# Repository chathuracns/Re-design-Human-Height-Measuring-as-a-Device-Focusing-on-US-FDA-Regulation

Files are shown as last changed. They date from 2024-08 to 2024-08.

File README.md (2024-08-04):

# Re-design-Human-Height-Measuring-as-a-Device-Focusing-on-US-FDA-Regulation

## **Device Classification and Premarket Notification:**

We have classified the device as a Class II medical device. In accordance with FDA regulations, a Premarket Notification (510(k)) submission is required for Class II devices. We have determined that our device is substantially equivalent to a legally marketed predicate device. This determination involved a comprehensive analysis of existing products, identifying both similarities and differences between them and our device.

## **Good Manufacturing Practices (GMP):**

We are in full compliance with the FDA's Quality System Regulation (QSR), which encompasses requirements for design controls, focusing on user safety, production, and process controls. We have adhered to rigorous documentation practices from the outset to ensure comprehensive record-keeping.

## **Design Controls:**

**Purpose:** Design controls are implemented to ensure the device is designed to meet user requirements and regulatory standards while mitigating risks.

- **Design and Development Planning:** We have completed three prototype iterations: a demonstration prototype, an alpha prototype, and a limited batch production run of 15 devices. Each prototype underwent three test cycles, leading to iterative improvements in quality.

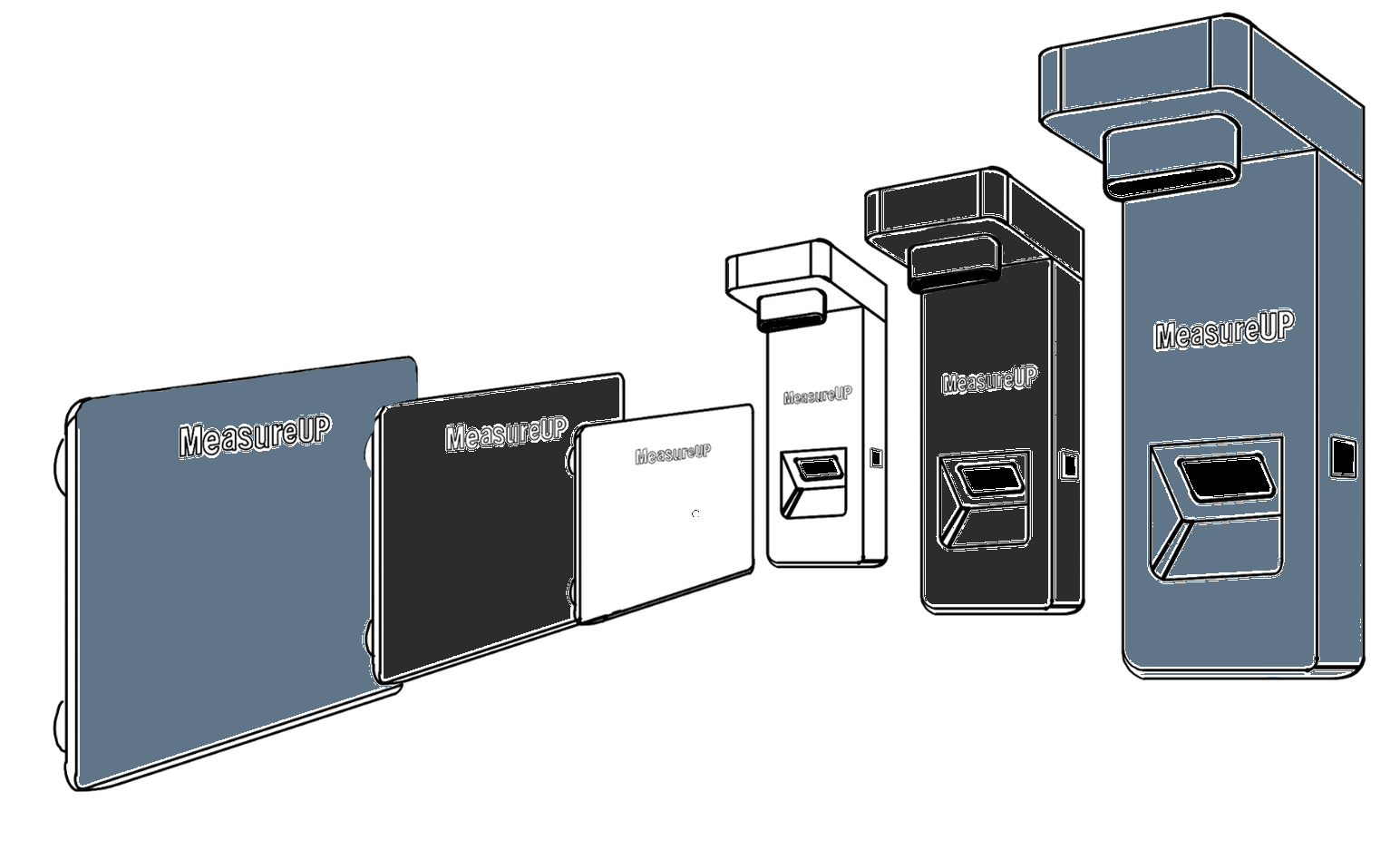
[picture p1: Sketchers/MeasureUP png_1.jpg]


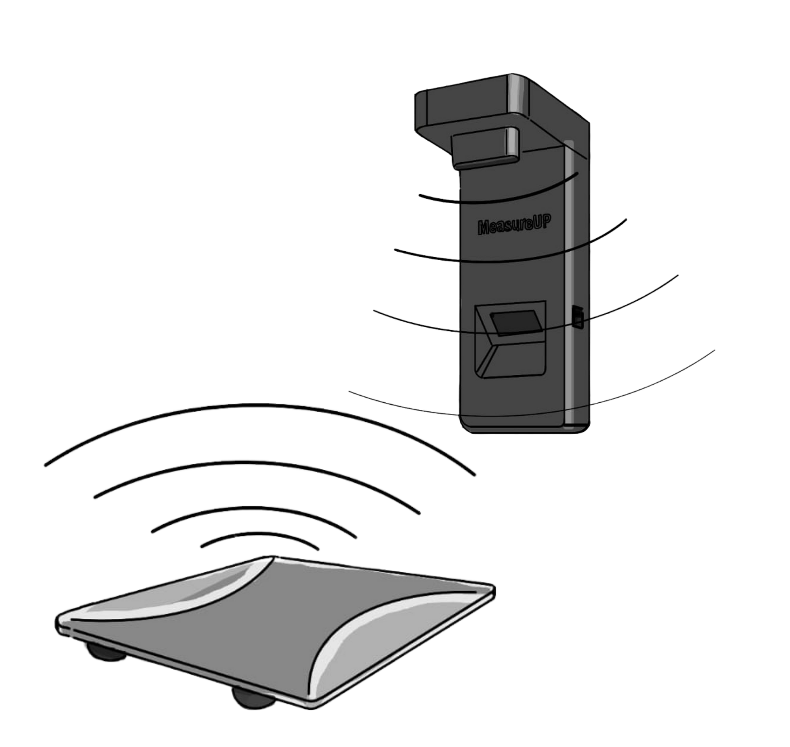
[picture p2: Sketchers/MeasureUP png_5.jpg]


- **Design Input:** The design was primarily developed to meet UNICEF's height measurement requirements for children, targeting a precision of approximately 1mm. Initially, the device exhibited a precision of 3cm, and we are working towards further refinement to meet these precision standards.
  
- **Design Output:** Documentation demonstrates that the design meets user requirements and regulatory criteria. We have documented improvements through three test cycles and various prototype stages.

- **Design Verification and Validation:** We ensure that the design meets all specified requirements through rigorous testing and evaluation. Achieving a precision of 3cm represents significant progress given the device's initial specifications.

## **Production and Process Controls:**

- **Process Validation:** The product enclosure has been optimized to maintain consistent printing quality.
  
- **Control of Production and Process Changes:** We have selected reputable production partners and documented the selection process accordingly.
  
- **Production Records:** We place significant emphasis on maintaining detailed production records.

- **Labeling:** The device adheres to appropriate labeling requirements, including user instructions, indications for use, and necessary warnings or precautions.

## **Document Controls:**

**Purpose:** We ensure that all documents related to the device’s design, manufacturing, and quality are properly controlled and maintained, particularly in relation to managing a 500,000 LKR grant which necessitated the management of approximately 100 documents.

**Document Creation and Review:** We develop and review key documents such as design specifications, manufacturing instructions, and quality control procedures. For instance, we have created and reviewed a Standard Operating Procedure (SOP) for sensor calibration, ensuring it is approved by the quality team.

**Document Changes:** We implement a structured process for managing document changes. 

**Document Storage and Retrieval:** Documents are stored in a secure, organized manner to facilitate easy retrieval. Electronic records of design and production documents are maintained in a document management system with version control.

---

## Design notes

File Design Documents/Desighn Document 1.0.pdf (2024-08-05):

# Improvements

1.Edges Design Modification:

Make the edges curved like this and remove the slope on the other side.

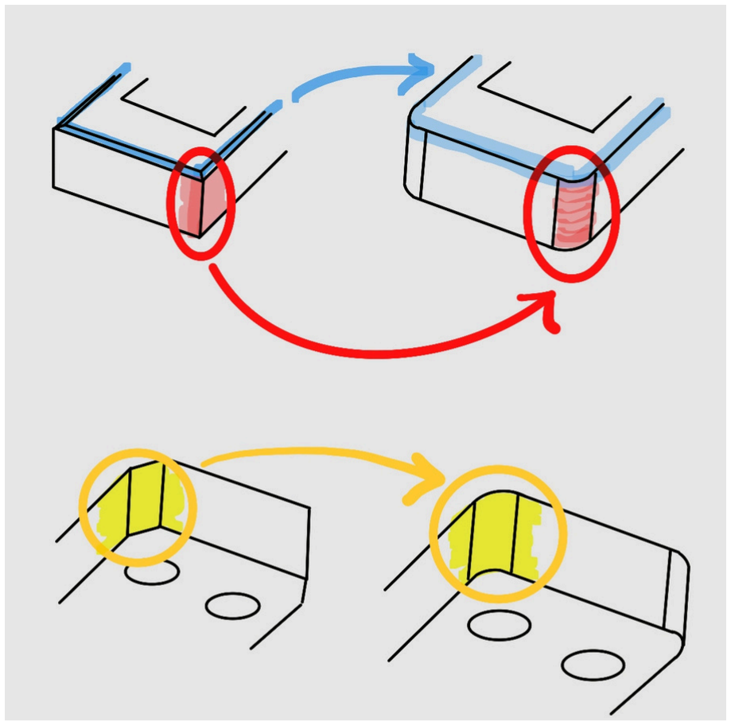
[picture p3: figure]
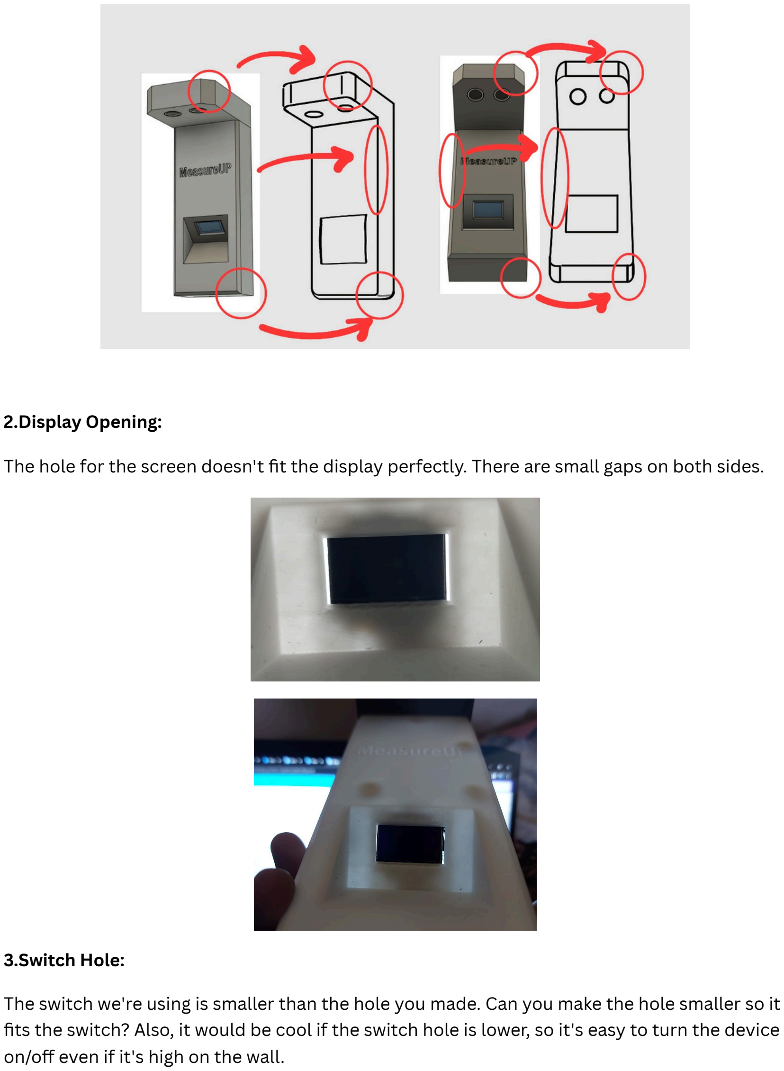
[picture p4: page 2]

2.Display Opening:

The hole for the screen doesn't fit the display perfectly. There are small gaps on both sides.

3.Switch Hole:

The switch we're using is smaller than the hole you made. Can you make the hole smaller so it fits the switch? Also, it would be cool if the switch hole is lower, so it's easy to turn the device on/off even if it's high on the wall.

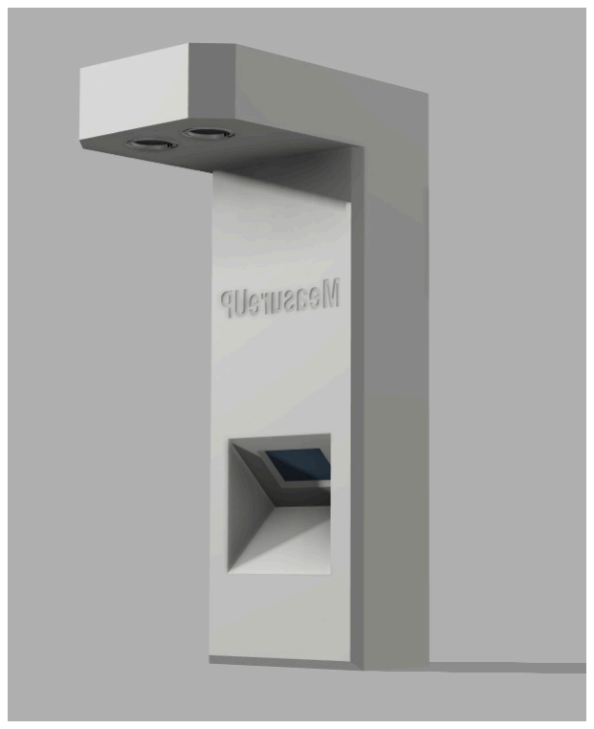
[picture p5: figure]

4.Battery Hole:

The magnets on both sides of the battery hole make it hard to put in the battery. Can you move one magnet up and the other down, so there's space in the middle for the battery?

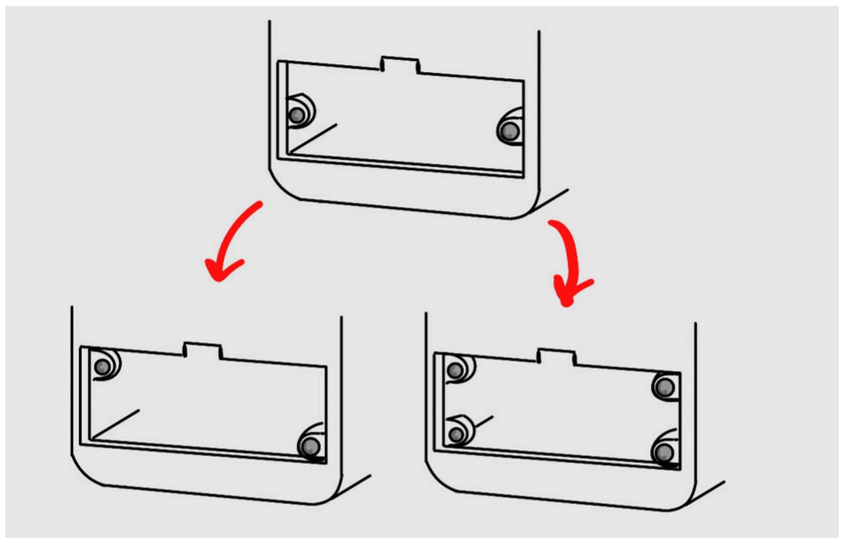
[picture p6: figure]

5.Back Cover:

The back cover only has three screws, and it bends when you press it. Maybe add more screws or move them around?

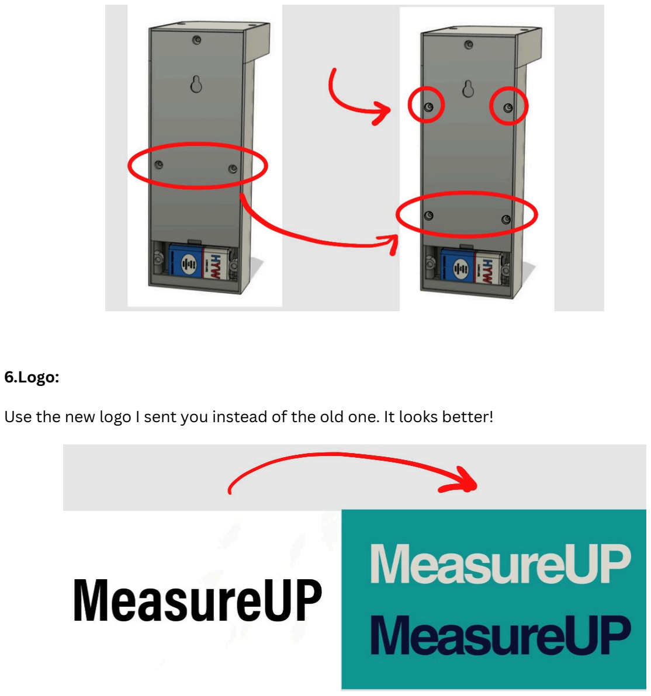
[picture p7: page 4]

6.Logo:

Use the new logo I sent you instead of the old one. It looks better!

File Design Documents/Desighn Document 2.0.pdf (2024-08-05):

1.Need to add an extended part to the ultrasonic sensor holes in order to control its sound beam. A sample SolidWorks file is attached below to provide an idea of its structure, but we need to figure out how to mount it to the previous structure. The dimensions of the clip are the same as those provided in the SolidWorks design.

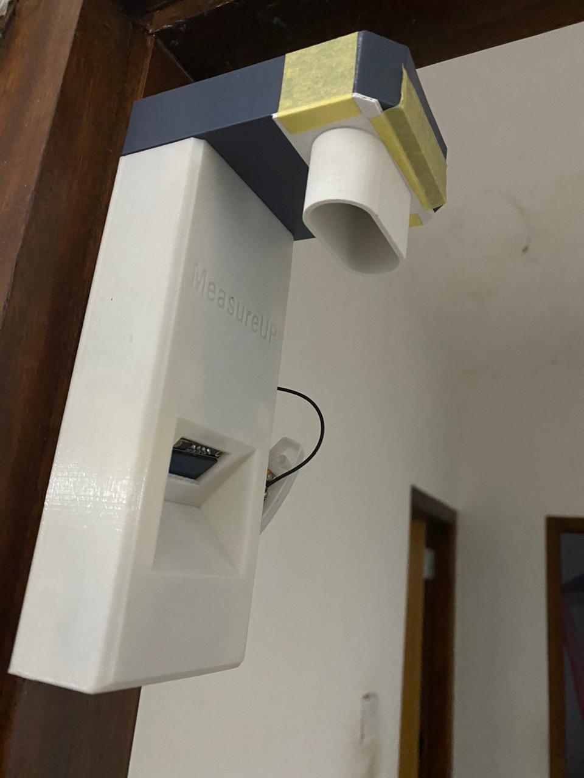
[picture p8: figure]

2.Need to modify the vertices and some edges of the display hole. Here is how it should be adjusted.

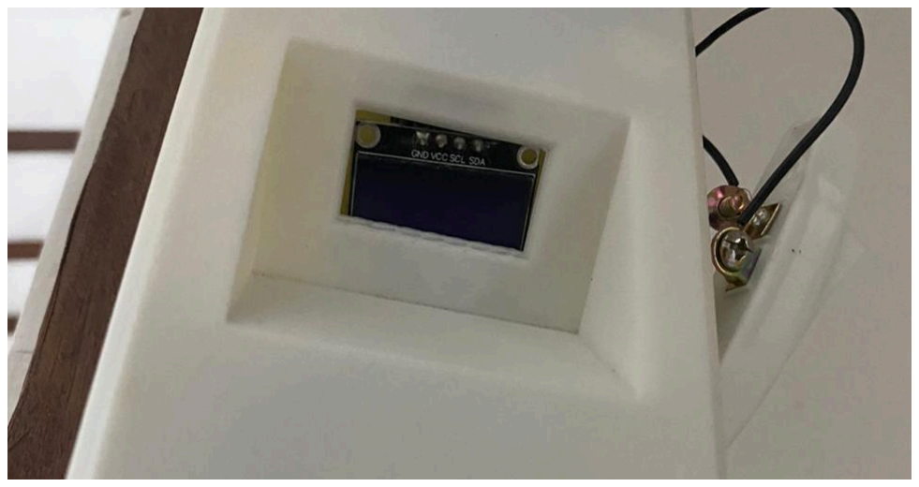
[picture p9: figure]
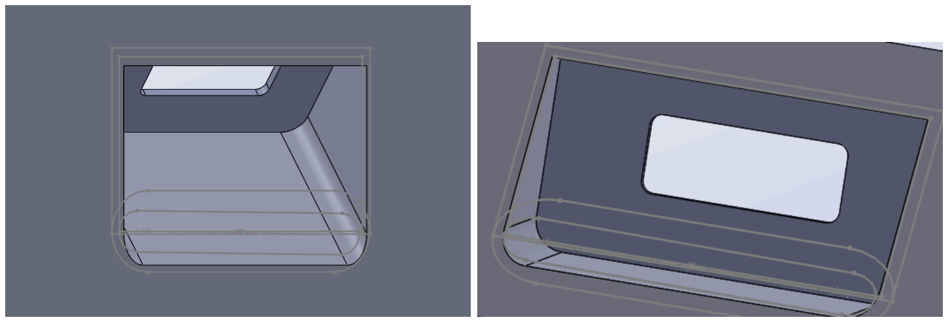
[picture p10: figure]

3.No need to change the dimensions of the OLED hole, as the newly ordered OLED fits well into it.

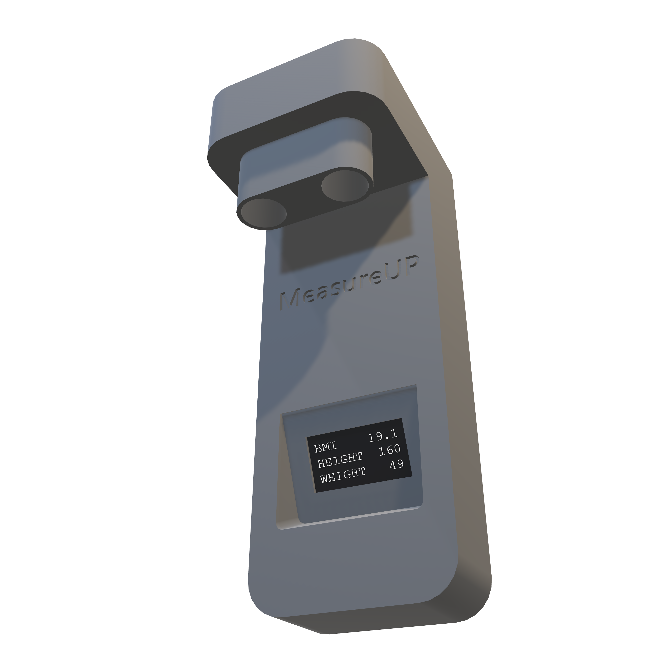
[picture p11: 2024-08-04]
Design Documents/Picture2.png

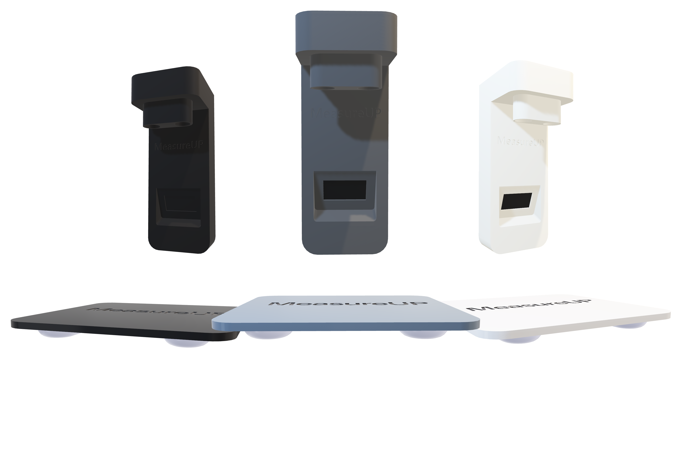
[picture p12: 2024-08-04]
Design Documents/Picture1.png

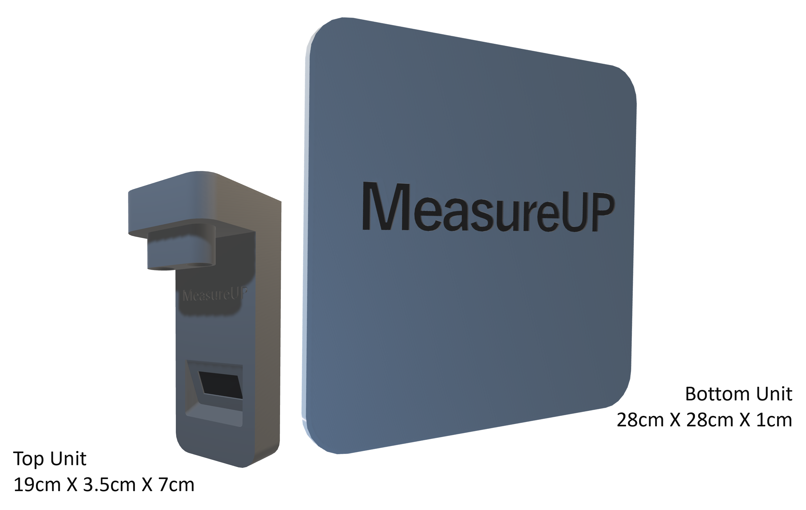
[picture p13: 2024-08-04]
Design Documents/Picture4.png

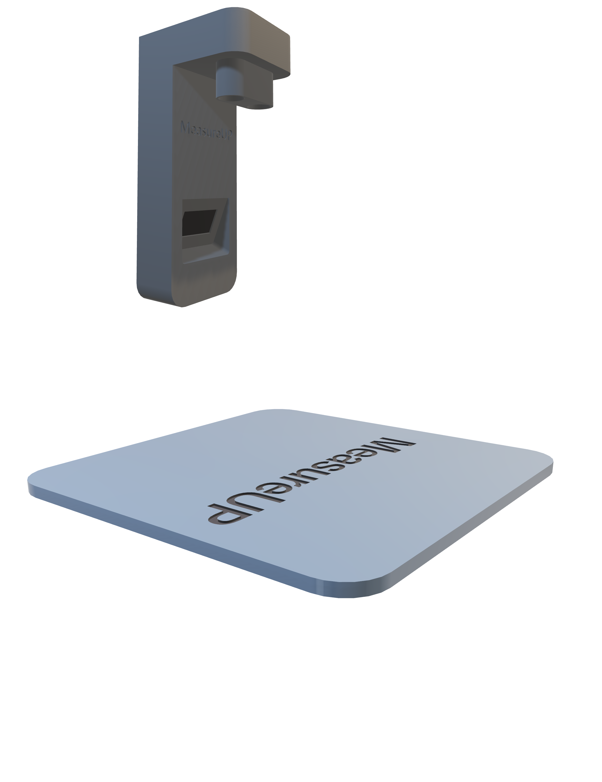
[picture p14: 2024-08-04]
Design Documents/Picture7.png

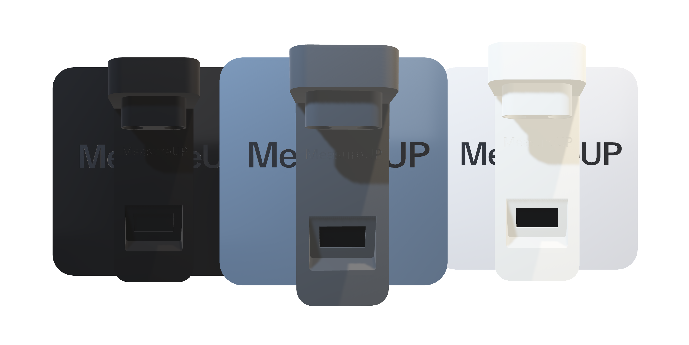
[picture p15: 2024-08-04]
Design Documents/Picture5.png

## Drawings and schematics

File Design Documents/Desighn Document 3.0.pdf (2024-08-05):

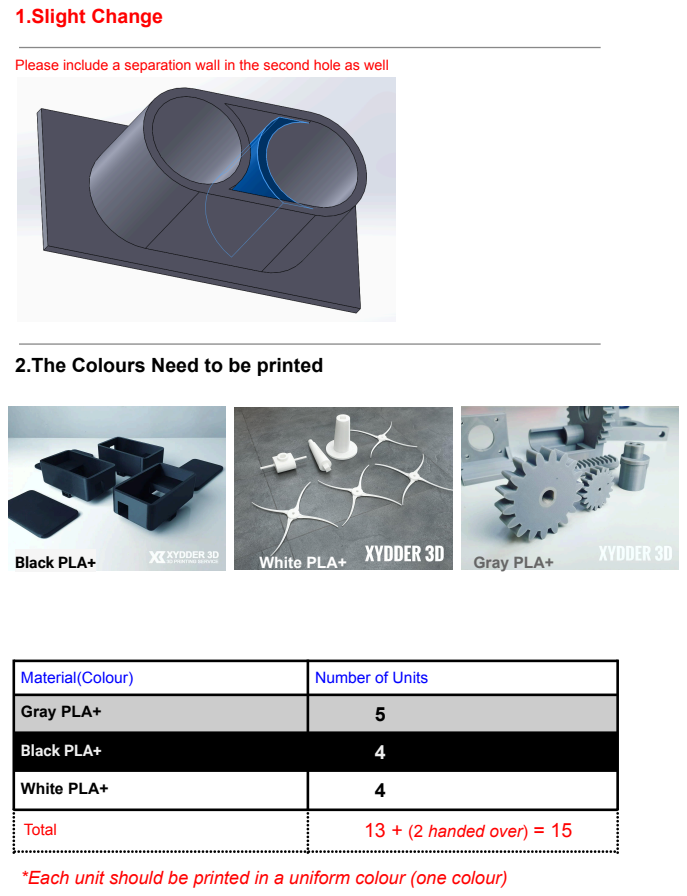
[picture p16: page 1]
1.Slight Change; Black PLA+; White PLA+; Gray PLA+; Total; 13 + (2 handed over) = 15

Please include a separation wall in the second hole as well

2.The Colours Need to be printed

Material(Colour) | Number of Units

Gray PLA+ | 5

Black PLA+ | 4

White PLA+ | 4

*Each unit should be printed in a uniform colour (one colour)

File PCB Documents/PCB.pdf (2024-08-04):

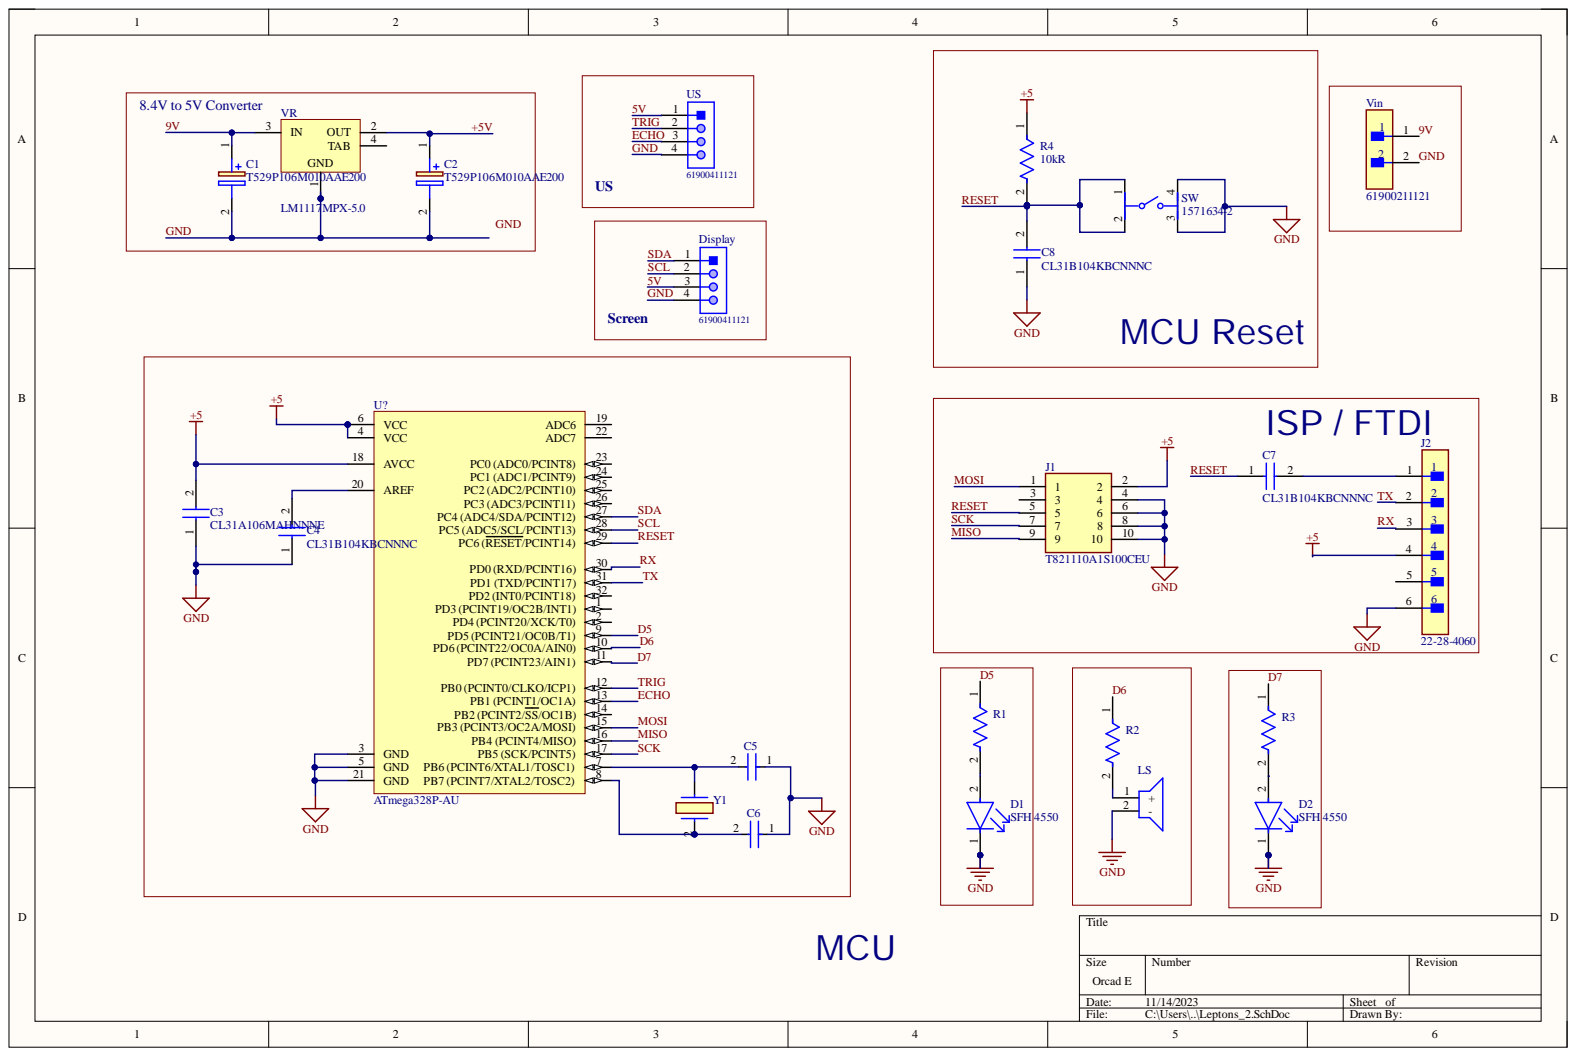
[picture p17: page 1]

1 8 | 2 3
2 0 | 2 4

Size Orcad E | Nu mb er | Revis i o n

Date: 1 1/1 4 /2 0 2 3 | Sheet o f
File: C:\User s\..\Lepto n s _ 2.S ch D o c | Drawn B y :

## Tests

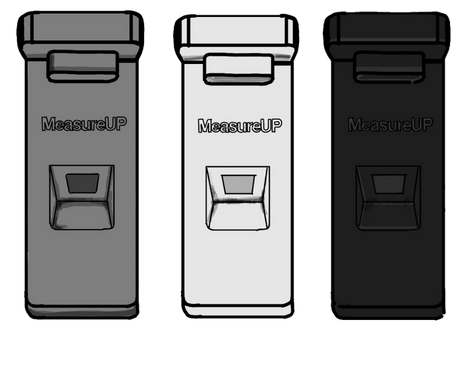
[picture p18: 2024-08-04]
Sketchers/MeasureUP png_7.jpg
